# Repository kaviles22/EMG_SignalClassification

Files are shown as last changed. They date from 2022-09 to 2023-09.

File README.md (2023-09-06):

# EMG Signal Classification
## ➡️ When using this resource, please cite the original publication:
- [Avilés-Mendoza, K., Gaibor-León, N. G., Asanza, V., Lorente-Leyva, L. L., & Peluffo-Ordóñez, D. H. (2023). A 3D Printed, Bionic Hand Powered by EMG Signals and Controlled by an Online Neural Network. Biomimetics, 8(2), 255.](https://doi.org/10.3390/biomimetics8020255)
## ✅ Abstract:
About 8% of the Ecuadorian population suffers some type of amputation of upper or lower limbs. Due to the high cost of a prosthesis and the fact that the salary of an average worker in the country reached 248 USD in August 2021, they experience a great labor disadvantage and only 17% of them are employed. Thanks to advances in 3D printing and the accessibility of bioelectric sensors, it is now possible to create economically accessible proposals. This work proposes the design of a hand prosthesis that uses electromyography (EMG) signals and neural networks for real-time control. The integrated system has a mechanical and electronic design, and the latter integrates artificial intelligence for control. To train the algorithm, an experimental methodology was developed to record muscle activity in upper extremities associated with specific tasks, using three EMG surface sensors. These data were used to train a five-layer neural network. the trained model was compressed and exported using TensorflowLite. The prosthesis consisted of a gripper and a pivot base, which were designed in Fusion 360 considering the movement restrictions and the maximum loads. It was actuated in real time thanks to the design of an electronic circuit that used an ESP32 development board, which was responsible for recording, processing and classifying the EMG signals associated with a motor intention, and to actuate the hand prosthesis. As a result of this work, a database with 60 electromyographic activity records from three tasks was released. The classification algorithm was able to detect the three muscle tasks with an accuracy of 78.67% and a response time of 80 ms. Finally, the 3D printed prosthesis was able to support a weight of 500 g with a safety factor equal to 15.

<p align="center">
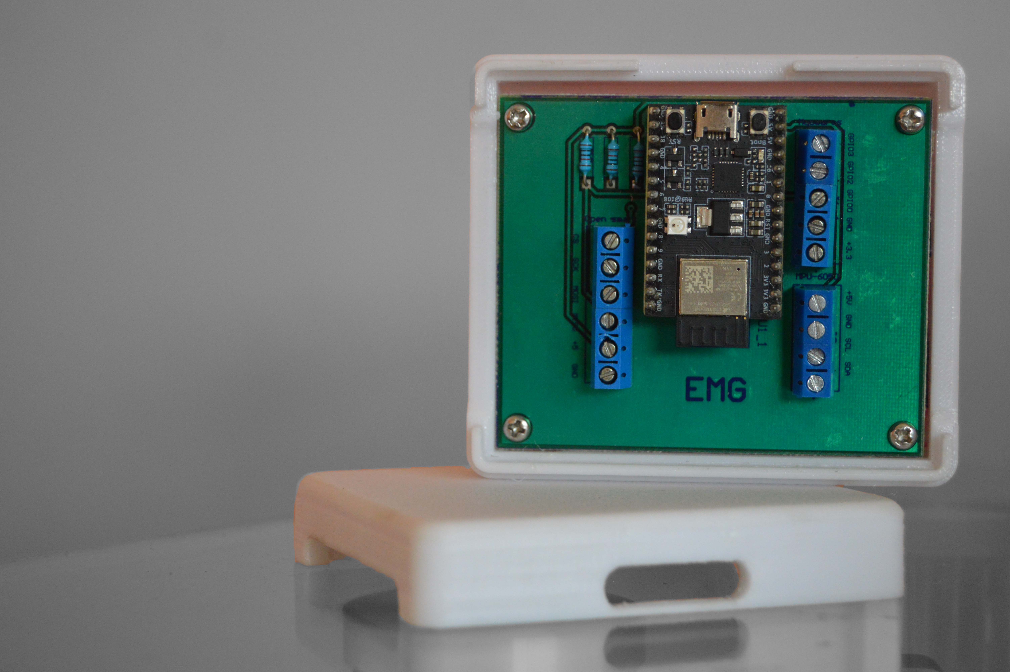
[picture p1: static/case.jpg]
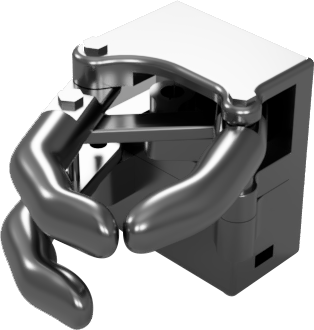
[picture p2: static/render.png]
 
</p>

## Introduction
This project aims to preprocess EMG signals and classify them into three classes using AI techniques to control a 3d printed prosthesis.
<p align="center">
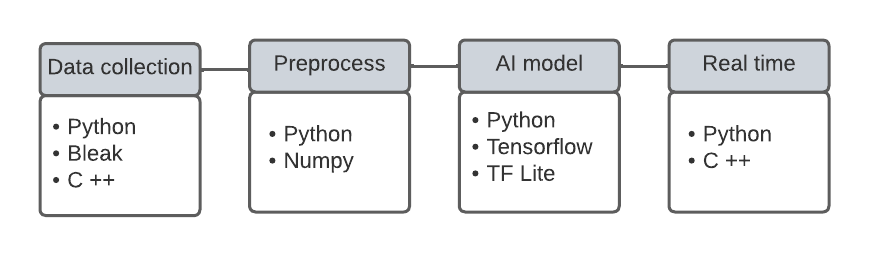
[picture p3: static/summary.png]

</p>

### Tools:
- [ESP32 C3](https://www.espressif.com/en/products/socs/esp32-c3)
- [MyoWare sensors](https://cdn.sparkfun.com/datasheets/Sensors/Biometric/MyowareUserManualAT-04-001.pdf)
- Servo motors
- [SD card module](https://create.arduino.cc/projecthub/electropeak/sd-card-module-with-arduino-how-to-read-write-data-37f390)
- Computer

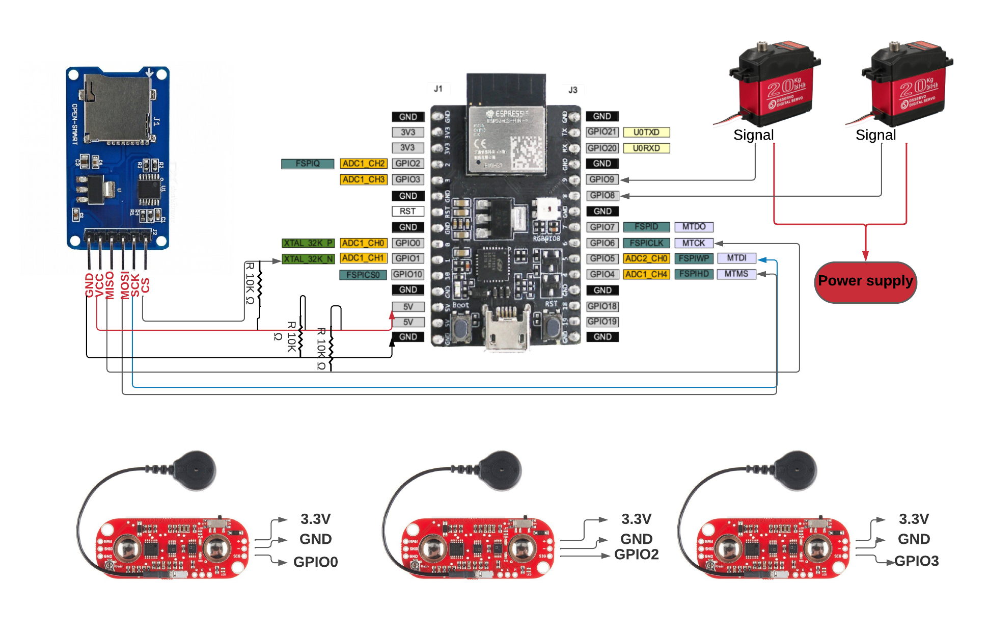
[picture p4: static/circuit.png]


## Data collection
[src/data_collection](https://github.com/kaviles22/EMG_SignalClassification/blob/main/src/data_collection)
<p align="center">
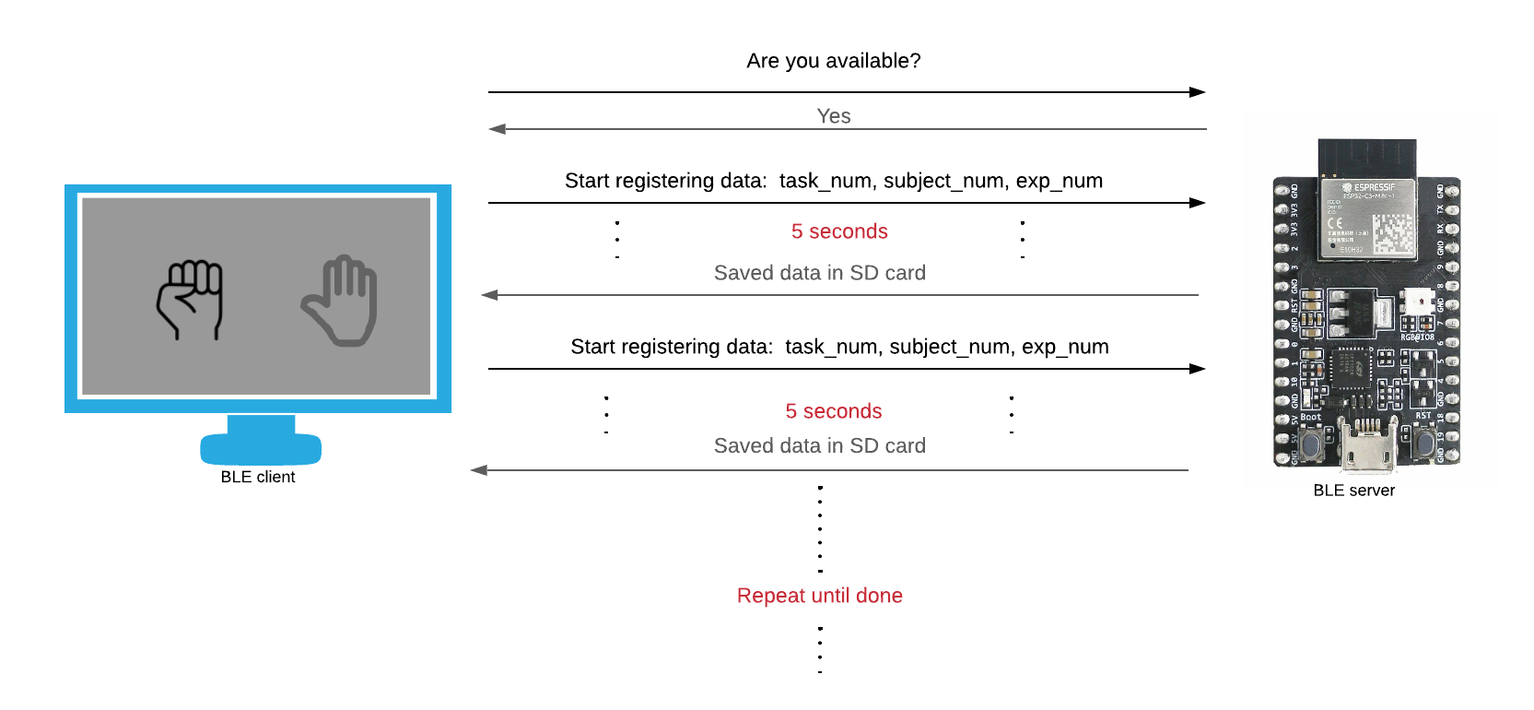
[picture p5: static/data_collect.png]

</p>

For this stage, a computer, running a python script and an Esp32c3, communicated using bluetooth low energy (BLE). The computer was in charge of indicating the tests subject when to start performing a certain muscular action. The esp32c3 was in charge of recording the emg data using 3 MyoWare sensors, labeling it and saving it on an SD card.

Note: the ideal would have been to send the data via bluetooth to the computer, however we were unable to find a way to do this quickly without affecting the data recording process which was done at a frequency of 1kHz. 

<p align="center">
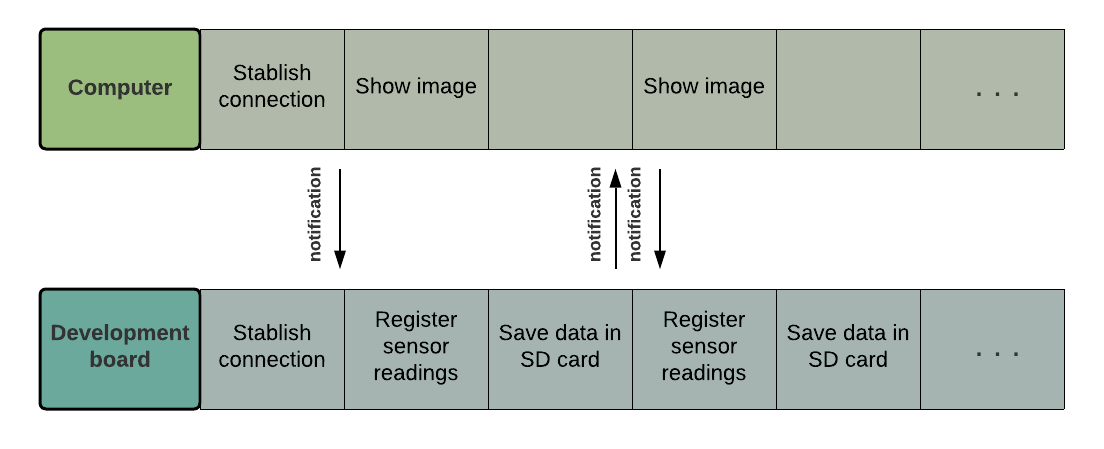
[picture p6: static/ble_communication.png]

</p>

### Screen visuals
The python script shows visual signs on the screen, representing each one of the actions. Between each recording interval, a resting sign appears, which means the test subject can stop performing the previous action.
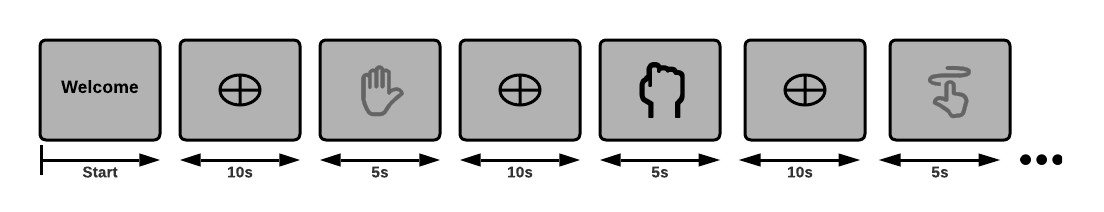
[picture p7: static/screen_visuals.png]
Screen visuals


## Preprocessing
Preprocessing data is an important step, specially when working with biological signals.

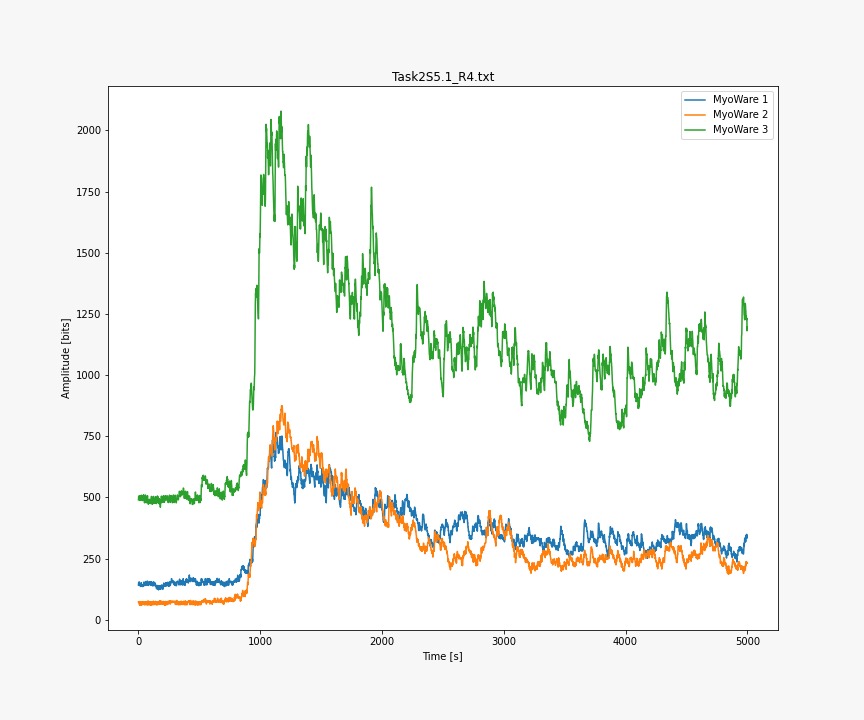
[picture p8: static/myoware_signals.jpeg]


### Filtering
To filter out the noise we used the RMS Envelope technique, which was calculated in a 50 ms wide window.
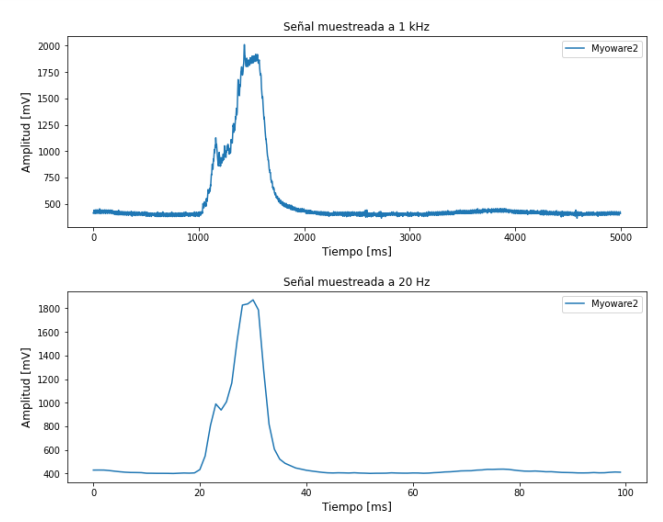
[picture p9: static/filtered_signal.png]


### Normalization
The peak dynamic method was used, which consists on representing each signal as a ratio of the peak value of that time window. Values were kept between [0, 1].
 <br />
 <br />
equation1

### Feature extraction
[src/feature_extraction/feature_extraction.ipynb](https://github.com/kaviles22/EMG_SignalClassification/blob/main/src/feature_extraction/feature_extraction.ipynb)<br />
Two approaches were analyzed:
1. Statistical features
2. RMS in time windows: extracting the rms value in subwindows.

## Training and converting the TF model to a TF Lite model
[src/train_model/train_test_model.py](https://github.com/kaviles22/EMG_SignalClassification/blob/main/src/train_model/train_test_model.py)<br />
A tensorflow model was trained and then converted into a TF Lite model. 

## Deploying model and testing it on real-time.
The whole pipeline was deployed on a ESP-C3 development board. The code was written in C++ and the model output was used to activate 2 servo motors to move the 3d printed prosthesis. 
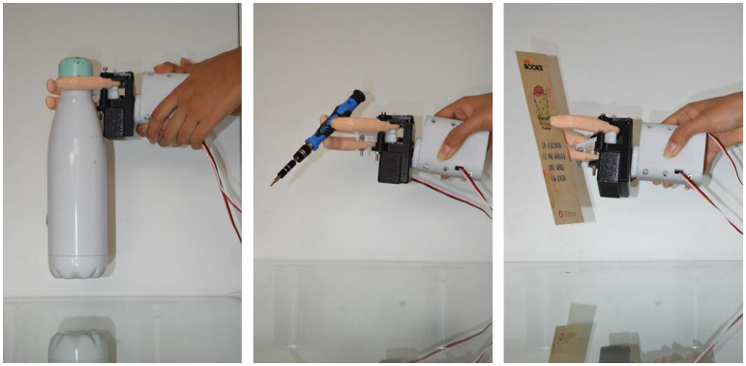
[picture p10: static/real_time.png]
Real time testing


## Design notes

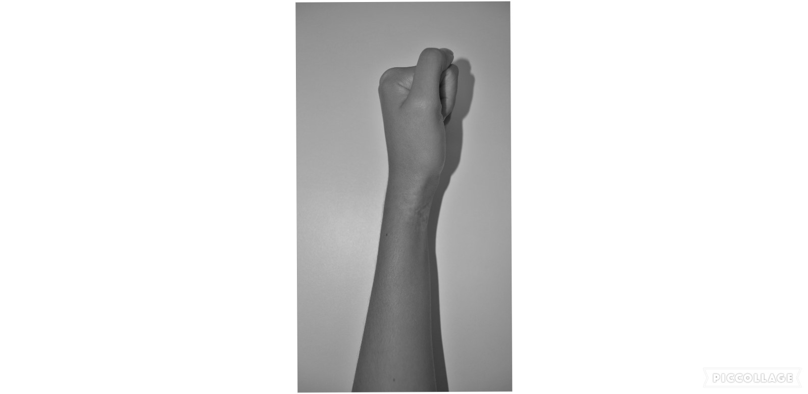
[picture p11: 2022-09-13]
static/task2.jpg

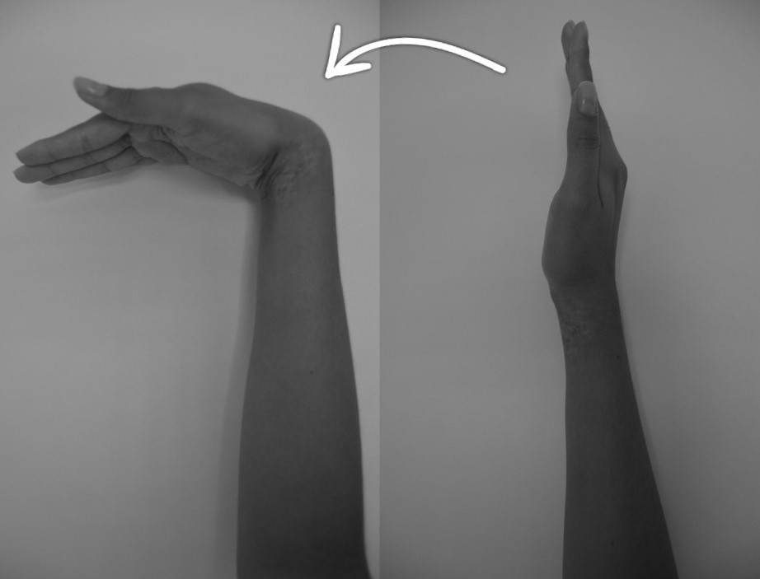
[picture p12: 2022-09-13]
static/task1.jpg

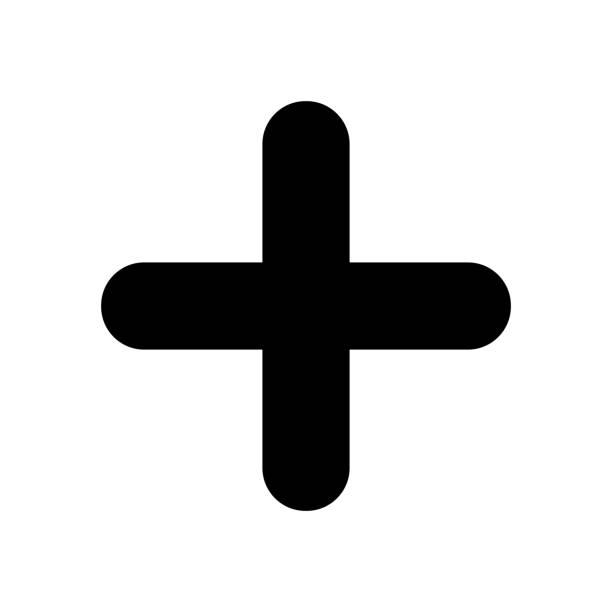
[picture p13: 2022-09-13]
static/baseline.jpg

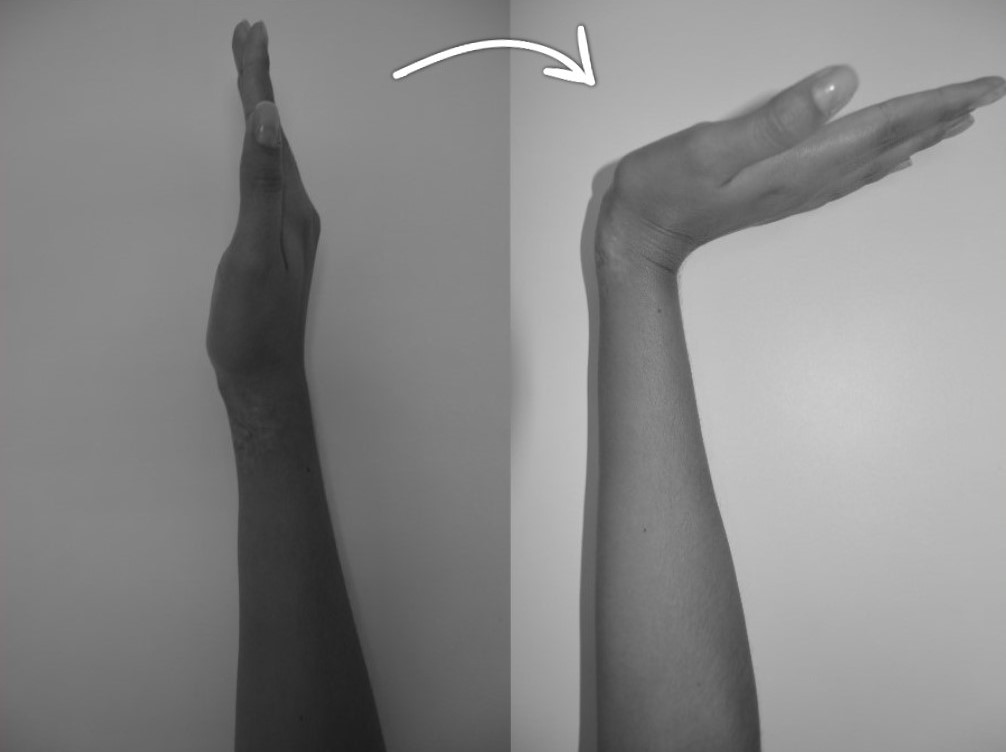
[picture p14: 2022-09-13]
static/task3.jpg

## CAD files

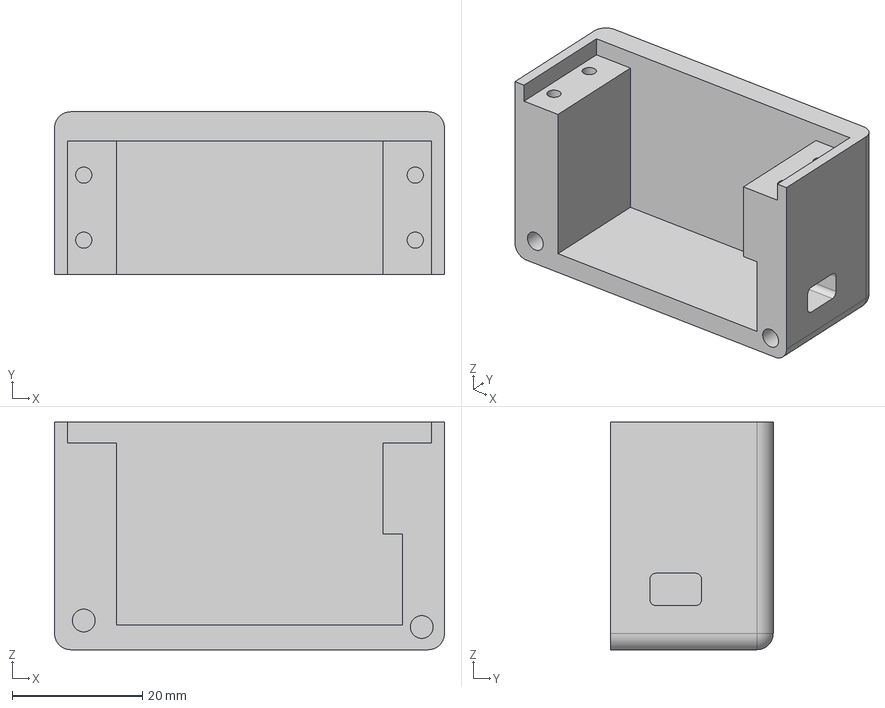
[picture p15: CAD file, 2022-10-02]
model/Gripper/front-cover.step
60.0 x 25.0 x 35.0 mm

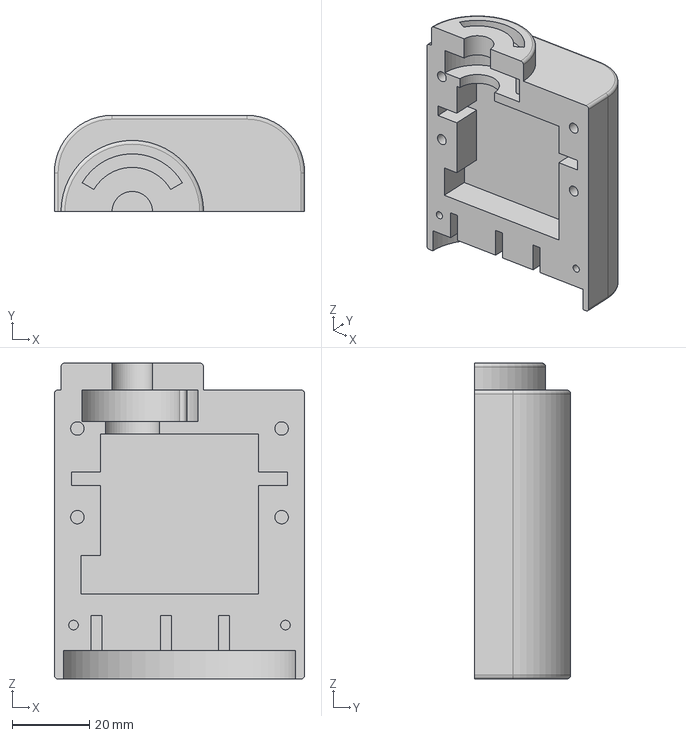
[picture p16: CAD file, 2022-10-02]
model/Rotation-Base/Bottom.step
65.0 x 25.0 x 82.0 mm

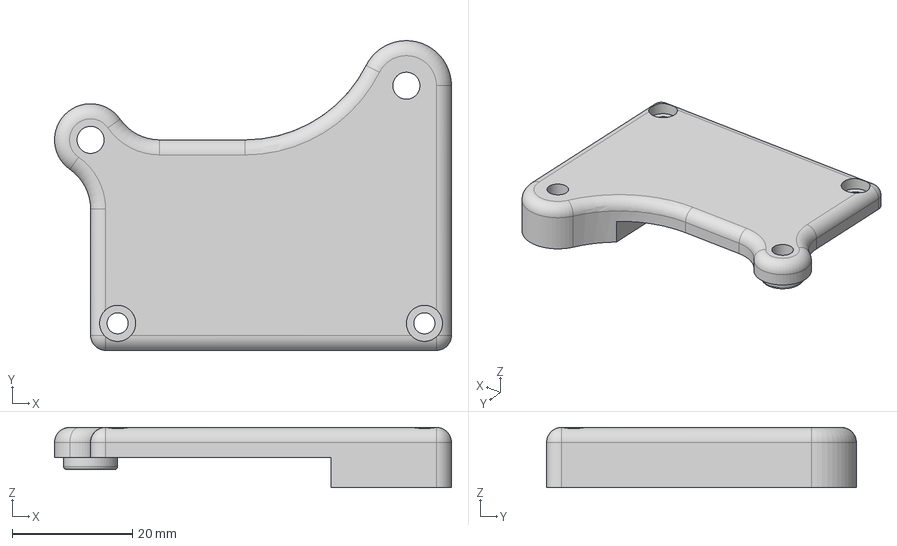
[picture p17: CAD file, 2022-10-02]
model/Gripper/upper-cover.step
66.0 x 51.5 x 10.0 mm

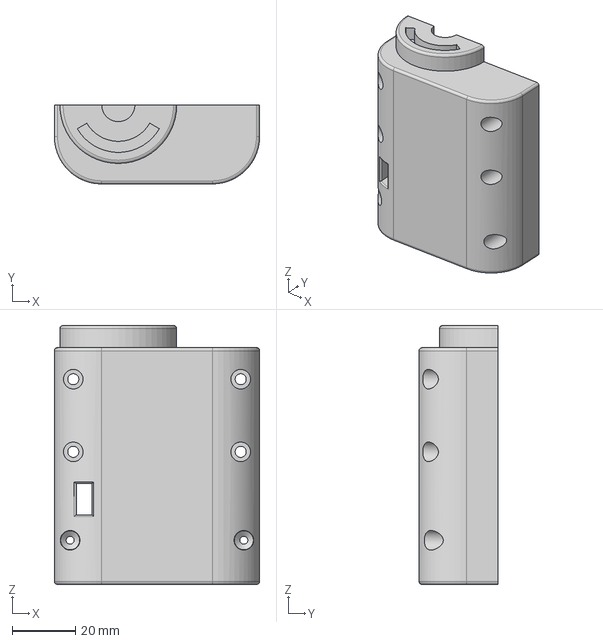
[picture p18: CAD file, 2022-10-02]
model/Rotation-Base/Top.step
65.0 x 25.0 x 82.0 mm

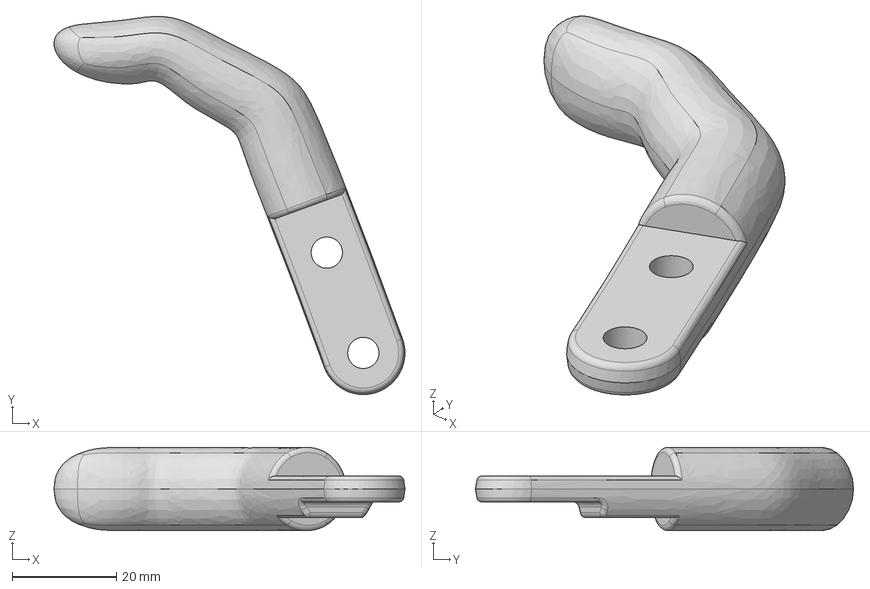
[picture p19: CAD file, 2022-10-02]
model/Gripper/mid-finger.step
67.4 x 72.6 x 16.0 mm

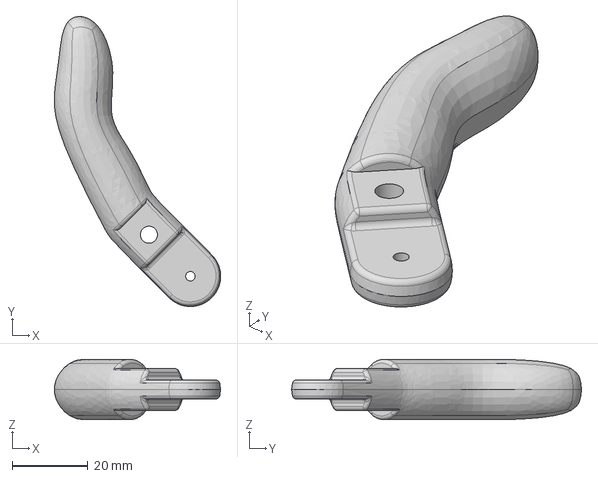
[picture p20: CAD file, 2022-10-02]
model/Gripper/thumb.step
43.9 x 76.6 x 15.9 mm

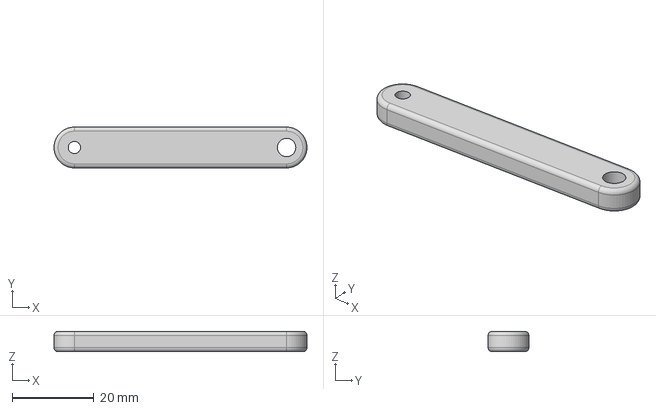
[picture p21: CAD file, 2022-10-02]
model/Gripper/finger-link.step
62.0 x 10.0 x 5.00 mm

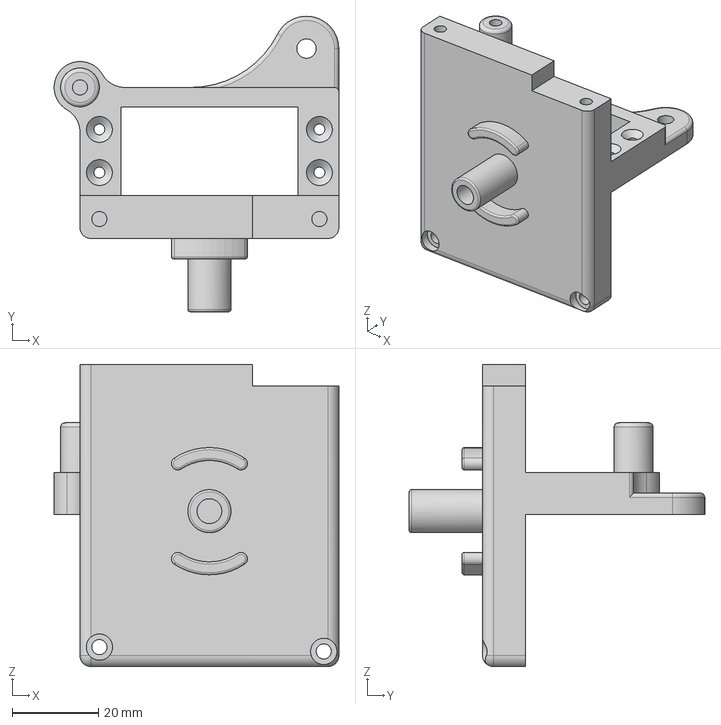
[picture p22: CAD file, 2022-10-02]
model/Gripper/back-cover.step
66.0 x 68.5 x 70.0 mm

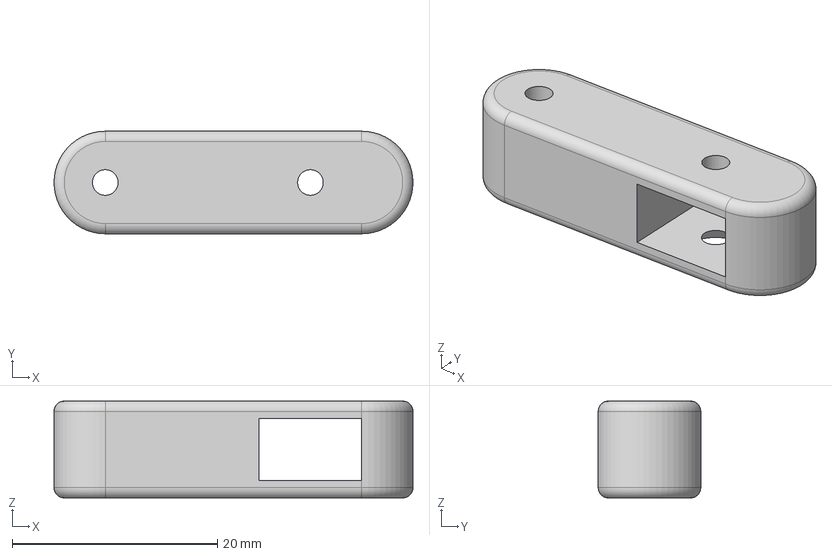
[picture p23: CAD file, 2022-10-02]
model/Gripper/finger-motorlink.step
35.0 x 10.0 x 9.45 mm

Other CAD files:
model/Gripper/index-finger.step

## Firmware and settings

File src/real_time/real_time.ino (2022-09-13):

#define ANGLE_MIN 0
#define ANGLE_MAX 0

#define OPEN_ANGLE  0
#define CLOSE_ANGLE 20

#define TURN_ANGLE1 0
#define TURN_ANGLE2 60
#define TURN_ANGLE3 120

/*Libraries*/
//Tensorflow model converted to C++
#include "modeldata.h"
//functions
#include "functions.h"

#include "servo.h"

//Tensorflow custom library for ESP32
#include <TensorFlowLite_ESP32.h>
//experimental versions of regular Tensorflow headers
#include "tensorflow/lite/experimental/micro/kernels/all_ops_resolver.h"
#include "tensorflow/lite/experimental/micro/micro_error_reporter.h"
#include "tensorflow/lite/experimental/micro/micro_interpreter.h"
#include "tensorflow/lite/schema/schema_generated.h"
#include "tensorflow/lite/version.h"


// Globals, used for compatibility with Arduino-style sketches.
namespace {
tflite::ErrorReporter* error_reporter = nullptr;
const tflite::Model* model = nullptr;
tflite::MicroInterpreter* interpreter = nullptr;
TfLiteTensor* input = nullptr;
TfLiteTensor* output = nullptr;
int inference_count = 0;
int last_angle = TURN_ANGLE1;

// Create an area of memory to use for input, output, and intermediate arrays.
// Finding the minimum value for your model may require some trial and error.
constexpr int kTensorArenaSize = 15 * 1024;
uint8_t tensor_arena[kTensorArenaSize];
}  // namespace

int this_predict = -1;
int last_predict = -1;
uint8_t turning_angle = 0;
/*Functions*/

void setup() {

  
  Serial.begin(115200);
  // Set up logging. Google style is to avoid globals or statics because of
  // lifetime uncertainty, but since this has a trivial destructor it's okay.
  // NOLINTNEXTLINE(runtime-global-variables)
  static tflite::MicroErrorReporter micro_error_reporter;
  error_reporter = &micro_error_reporter;

  // Map the model into a usable data structure. This doesn't involve any
  // copying or parsing, it's a very lightweight operation.
  model = tflite::GetModel(prosthetic_model_data);
  if (model->version() != TFLITE_SCHEMA_VERSION) {
    error_reporter->Report(
        "Model provided is schema version %d not equal "
        "to supported version %d.",
        model->version(), TFLITE_SCHEMA_VERSION);
    return;
  }

  // This pulls in all the operation implementations we need.
  // NOLINTNEXTLINE(runtime-global-variables)
  static tflite::ops::micro::AllOpsResolver resolver;

  // Build an interpreter to run the model with.
  static tflite::MicroInterpreter static_interpreter(
      model, resolver, tensor_arena, kTensorArenaSize, error_reporter);
  interpreter = &static_interpreter;

  // Allocate memory from the tensor_arena for the model's tensors.
  TfLiteStatus allocate_status = interpreter->AllocateTensors();
  if (allocate_status != kTfLiteOk) {
    error_reporter->Report("AllocateTensors() failed");
    return;
  }

  // Obtain pointers to the model's input and output tensors.
  input = interpreter->input(0);
  output = interpreter->output(0);

  // Keep track of how many inferences we have performed.
  inference_count = 0;
  setup_servo();

}



void loop() {
  
  //{0.179, 0.551, 0.897, 0.565, 0.125, 0.601, 0.659, 0.581, 0.167, 0.575, 0.787, 0.712};
  //{0.125, 0.799, 0.475, 0.269, 0.052, 0.797, 0.741, 0.641, 0.440, 0.320, 0.249, 0.232};
  float data1[12] = {0.01748063255033152,0.6471331786528353,0.773371718450464,0.5495089664613995,0.07838395424159811,0.5914132305547034,0.5777429837032254,0.3967241023854958,0.07118843288668772,0.3587160835843334,0.6469245447925207,0.4376814438882512};
  input->data.f = prelim_collection();

  TfLiteStatus invoke_status = interpreter->Invoke();
  if (invoke_status != kTfLiteOk) {
    error_reporter->Report("Invoke failed on x_val");
    return;
  }
  /*Serial.print("INPUT    DATA: ");
  for(int i = 0; i<12;i++){
     Serial.print(input->data.f[i]);
     Serial.print(",");
   }
   Serial.println(" ");
    Serial.println("************************************************");*/
    Serial.println("----------------------------------");
    Serial.print("MODEL OUTPUT: Open:");
    Serial.print(output->data.f[0]);
    Serial.print(", Turn: ");
    Serial.print(output->data.f[1]);
    Serial.print(", Close: ");
    Serial.print(output->data.f[2]);
    Serial.print(", Rest: ");
    Serial.println(output->data.f[3]);

    for (int i = 0; i < 3; i++) {
    if (output->data.f[i] > 0.8) this_predict = i;
    }
    //If the new prediction is the same as the previous one servos should not move.
    if(this_predict == last_predict){
      this_predict = -1;
    }
    switch(this_predict){
      case(0):
        //CERRAR MANO
        set_servo_mov(CLOSE_ANGLE);
          Serial.println("CLOSING HAND");
        /*if (get_servo_mov() != CLOSE_ANGLE){
          set_servo_mov(CLOSE_ANGLE);
          Serial.println("CLOSING HAND");
        }*/
        break;
      case(1):
        Serial.println("TURNING HAND");
        switch(get_servo_turn()){
          case(TURN_ANGLE1):
            last_angle = get_servo_turn();
            set_servo_turn(TURN_ANGLE2);
            Serial.print("Last angle: ");
            Serial.print(last_angle);
            Serial.print(", ");
            Serial.print("Moving to: ");
            Serial.println(TURN_ANGLE2);
            break;
          case(TURN_ANGLE2):
            if (last_angle == TURN_ANGLE1){
              set_servo_turn(TURN_ANGLE3);
              Serial.print("Last angle: ");
              Serial.print(last_angle);
              Serial.print(", ");
              Serial.print("Moving to: ");
              Serial.println(TURN_ANGLE3);
            } else if (last_angle == TURN_ANGLE3){
              set_servo_turn(TURN_ANGLE1);
              Serial.print("Last angle: ");
              Serial.print(last_angle);
              Serial.print(", ");
              Serial.print("Moving to: ");
              Serial.println(TURN_ANGLE1);
            }
            break;
          case(TURN_ANGLE3):
            last_angle = get_servo_turn();
            set_servo_turn(TURN_ANGLE2);
            Serial.print("Last angle: ");
            Serial.print(last_angle);
            Serial.print(", ");
            Serial.print("Moving to: ");
            Serial.println(TURN_ANGLE2);
            break;
        }
        break;
        case(2):
        //ABRIR MANO
        set_servo_mov(OPEN_ANGLE);
         Serial.println("OPENING HAND");
        /*if (get_servo_mov() != OPEN_ANGLE){
          set_servo_mov(OPEN_ANGLE);
          Serial.println("OPENING HAND"); 
        }*/
        break;
      }
   this_predict = -1;
  // Output array = [class0, class1, class2] --> Class0: musculo adentro, Class1: musculo afuera, Class2: descanso
  float y_val = output->data.f[0];
  inference_count += 1;
  if (inference_count >= 5000) inference_count = 0;

}

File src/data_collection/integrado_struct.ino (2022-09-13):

/*
Note: redefine spi communications pins in the SPI.cpp library file before the spiAttach functions as follows for ESP32C3 compatibility

_sck = 5;
_miso = 6;
_mosi = 4;
_ss = 1;

spiAttachSCK(_spi, _sck);
spiAttachMISO(_spi, _miso);
spiAttachMOSI(_spi, _mosi);

*/
//Include libraries for I2c communication with MPU6050 sensor
#include <Adafruit_MPU6050.h>
#include <Adafruit_Sensor.h>
#include <Wire.h>

//Include libraries for SPI communication with SD card
#include "FS.h"
#include "SD.h"
#include "SPI.h"

//Include Ble libraries
#include <BLEDevice.h>
#include <BLEUtils.h>
#include <BLEServer.h>

//Define pins por I2C COMMUNICATION WITH MPU6050
#define I2C_SCL 8
#define I2C_SDA 9

//Define pins for ADC read (MyoWare1 - MyoWare2 - MyoWare3)
#define pin_MW1 0
#define pin_MW2 2
#define pin_MW3 3

//Define Ble variables
#define SERVICE_UUID        "4fafc201-1fb5-459e-8fcc-c5c9c331914b"
#define CHARACTERISTIC_UUID "beb5483e-36e1-4688-b7f5-ea07361b26a8"

#define TIME             5    //seconds
#define FRECUENCY        1000 //Hz 
#define DATA_PER_SENSOR  TIME*FRECUENCY

Adafruit_MPU6050 mpu;
int              count;
unsigned long    Start;
//unsigned long    Start1;

uint8_t          task_number;
uint8_t          subj_number;
uint8_t          exp_number;
uint8_t          rep_number;
char             file_name_dat[25];

struct emg_data {
    uint16_t  mw1;
    uint16_t  mw2;
    uint16_t  mw3;
    float     ax;
    float     ay;
    float     az;
    float     gx;
    float     gy;
    float     gz;
};

emg_data        emg_array[DATA_PER_SENSOR];

class MyCallbacks: public BLECharacteristicCallbacks {
    void onWrite(BLECharacteristic *pCharacteristic) {
      std::string value = pCharacteristic->getValue();
      //Serial.println(value.length());
      if (value.length() == 4) {
        task_number = (uint8_t)value[0];
        subj_number = (uint8_t)value[1];
        exp_number  = (uint8_t)value[2];
        rep_number  = (uint8_t)value[3];
        sprintf(file_name_dat, "/DAT/Task%d/S%d.%d_R%d.dat", task_number, subj_number, exp_number, rep_number);
        Serial.println(file_name_dat); 
        Start = millis();
        //Start1 = millis();
        while(count<DATA_PER_SENSOR){
          sensors_event_t a, g, temp;
          mpu.getEvent(&a, &g, &temp);

          emg_array[count].mw1  = analogRead(pin_MW1);
          emg_array[count].mw2  = analogRead(pin_MW2);
          emg_array[count].mw3  = analogRead(pin_MW3);

          emg_array[count].ax   = a.acceleration.x;
          emg_array[count].ay   = a.acceleration.y;
          emg_array[count].az   = a.acceleration.z;

          emg_array[count].gx   = g.gyro.x;
          emg_array[count].gy   = g.gyro.y;
          emg_array[count].gz   = g.gyro.z;
          count++;
          delay(1);
        }
        Serial.println(millis() - Start);           
        File file_dat = SD.open(file_name_dat, FILE_WRITE);
        if(!file_dat){
          Serial.println("Failed to open file for writing");
        }
        Serial.println(DATA_PER_SENSOR);
        for (int i = 0; i < DATA_PER_SENSOR; i++) {
          file_dat.write((const uint8_t *)&emg_array[i], sizeof(emg_array[i]));
        }
        file_dat.close();
        Serial.println("-- OVER --");
        //Serial.println(millis() - Start1);
      }
      pCharacteristic->setValue("File saved");
      count = 0;
    }
};

void setup_BLE(){
  BLEDevice::init("MyESP32");
  BLEServer *pServer = BLEDevice::createServer();

  BLEService *pService = pServer->createService(SERVICE_UUID);

  BLECharacteristic *pCharacteristic = pService->createCharacteristic(
                                         CHARACTERISTIC_UUID,
                                         BLECharacteristic::PROPERTY_READ |
                                         BLECharacteristic::PROPERTY_WRITE 
                                       );

  pCharacteristic->setCallbacks(new MyCallbacks());

  pCharacteristic->setValue("Hello World");
  pService->start();

  BLEAdvertising *pAdvertising = pServer->getAdvertising();
  pAdvertising->start();
  }

void createDir(fs::FS &fs, const char * path){
    Serial.printf("Creating Dir: %s\n", path);
    if(fs.mkdir(path)){
        Serial.println("Dir created");
    } else {
        Serial.println("mkdir failed");
    }
}

void setup_MPU6050(){
    while (!Serial)
    delay(10); // will pause Zero, Leonardo, etc until serial console opens
  Wire.begin(I2C_SDA, I2C_SCL);
  Wire.setClock(400000);

  if (!mpu.begin(0x68, &Wire, 0)) {
    Serial.println("Failed to find MPU6050 chip");
    while (1) {
      delay(10);
    }
  }
  Serial.println("MPU6050 Found!");
  mpu.setAccelerometerRange(MPU6050_RANGE_8_G);
  mpu.setGyroRange(MPU6050_RANGE_500_DEG);
  mpu.setFilterBandwidth(MPU6050_BAND_5_HZ);
  
}

void setup_ADC(uint8_t pin1, uint8_t pin2, uint8_t pin3){
  pinMode(pin1, INPUT);
  pinMode(pin2, INPUT);
  pinMode(pin3, INPUT);
  analogSetClockDiv(1);
}

void setup_SD(){
  if(!SD.begin(1)){
    Serial.println("Card Mount Failed");
    return;
  }
  uint8_t cardType = SD.cardType();
  if(cardType == CARD_NONE){
    Serial.println("No SD card attached");
    return;
  }else{
    Serial.println("SD card found");
    }
  
  uint64_t cardSize = SD.cardSize() / (1024 * 1024);
  Serial.printf("SD Card Size: %lluMB\n", cardSize);
}

void setup(void) {
  Serial.begin(115200);

  //Setup for BLE
  setup_BLE();
  
  //Setup for MPU6050 (I2C)
 //setup_MPU6050();  

  //Setup for ADC sensors
  setup_ADC(pin_MW1, pin_MW2, pin_MW3);

  //Setup for SD card (SPI)
  setup_SD();
  
  count = 0;
  delay(100);
}

void loop() {

  delay(50000);
}

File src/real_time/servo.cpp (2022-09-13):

#include "servo.h"

ISR_servo_t servo_mov  = {-1, PIN_SERVO_MOV};
ISR_servo_t servo_turn = {-1, PIN_SERVO_TURN};

void setup_servo(){
  
  ESP32_ISR_Servos.useTimer(USE_ESP32_TIMER_NO);
  servo_mov.servoIndex  = ESP32_ISR_Servos.setupServo(servo_mov.servoPin, MIN_MICROS, MAX_MICROS);
  servo_turn.servoIndex = ESP32_ISR_Servos.setupServo(servo_turn.servoPin, MIN_MICROS, MAX_MICROS);

}

void set_servo_mov(uint8_t servo_pos){
  ESP32_ISR_Servos.setPosition(servo_mov.servoIndex, servo_pos);  
}

void set_servo_turn(uint8_t servo_pos){
  ESP32_ISR_Servos.setPosition(servo_turn.servoIndex, servo_pos);  
}

int get_servo_mov(){
  return ESP32_ISR_Servos.getPosition(servo_mov.servoIndex);
  }

int get_servo_turn(){
  return ESP32_ISR_Servos.getPosition(servo_turn.servoIndex);
  }

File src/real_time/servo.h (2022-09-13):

#ifndef SERVO_HANDLER_H_
#define SERVO_HANDLER_H_ //header guard to prevent adding it multiple times

#define TIMER_INTERRUPT_DEBUG       1
#define ISR_SERVO_DEBUG             1
#define USE_ESP32_TIMER_NO          1

#define PIN_SERVO_MOV       5
#define PIN_SERVO_TURN      6

/*#define NUM_SERVOS          2 
Used to create an array of unitialized servos represented by the struct defined further below
*/

#define MIN_MICROS      544
#define MAX_MICROS      2400

#include "ESP32_C3_ISR_Servo.h"

typedef struct
{
  int     servoIndex;
  uint8_t servoPin;
} ISR_servo_t;

void setup_servo();
void set_servo_mov(uint8_t servo_pos);
void set_servo_turn(uint8_t servo_pos);
int get_servo_mov();
int get_servo_turn();
#endif 
